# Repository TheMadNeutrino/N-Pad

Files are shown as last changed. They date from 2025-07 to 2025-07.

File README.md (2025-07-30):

N-Pad

The N-Pad is a 7-key macropad, equipped with a rotary encoder, OLED screen and 16 addressable LEDs. The heart of this pad is XIAO RP2040, controlled via KMK firmware.
N-Pad compounds of 3 main elements: PCB, Bottom (main) part of the case and the top part.

Features:

    -6 + 1 keys with awesome functions
    -Rotary encoder to modify volume and MUTE function when pressed (the 7th key).
    -128x32 OLED screen displaying the volume level
    -16 addressable LEDs (6 right under the keys and rest and the back side of PCB for even brighter and smoother backlight, fancy light at the USB port too)
    - Years of big software updates coming!

Model of the N-Pad:

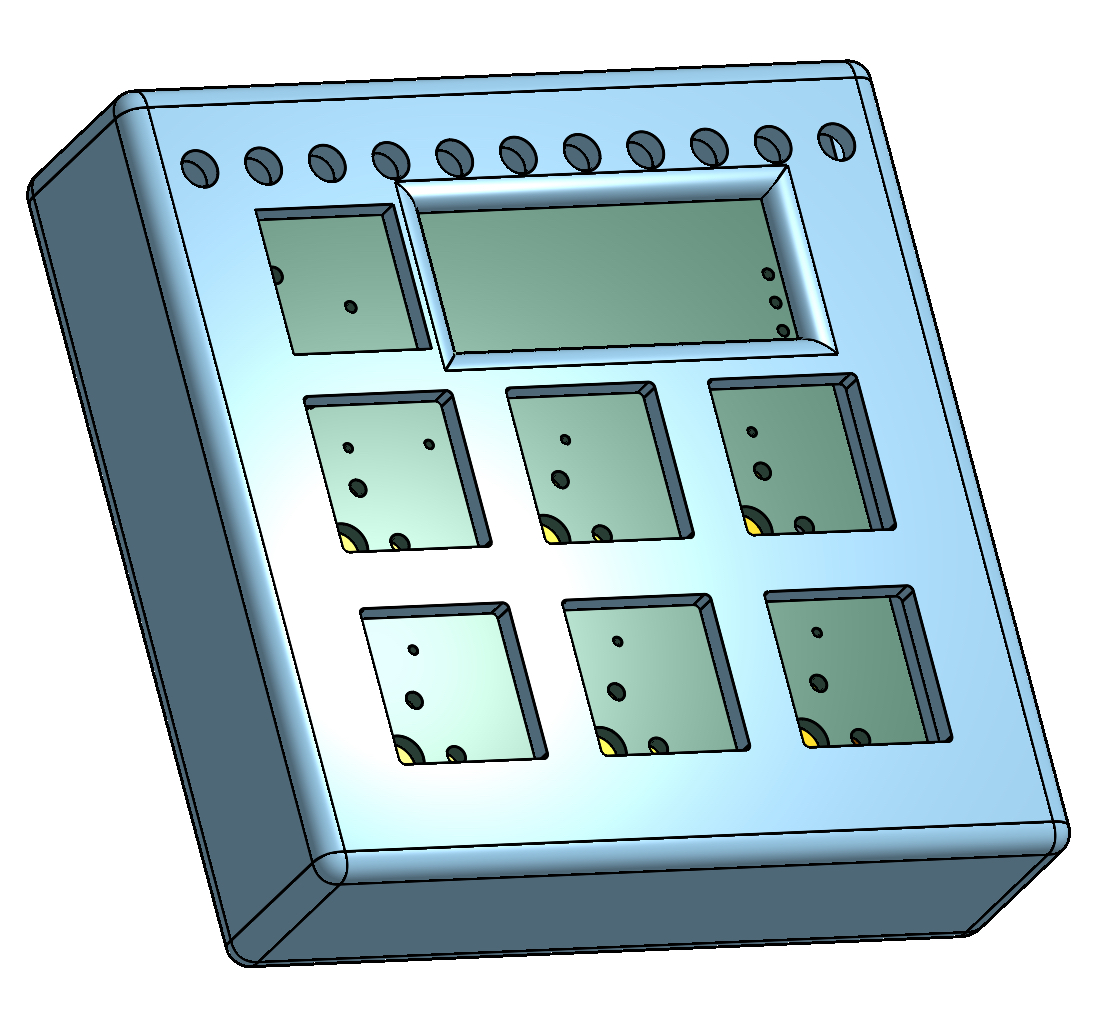
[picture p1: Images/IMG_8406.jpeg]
Model


The case is from 2 parts: The bottom part (includes space for PCB with raised platforms). The top has cutouts for key switches, rotary encoder as well as OLED screen and can be easily taken off.

Bottom part:
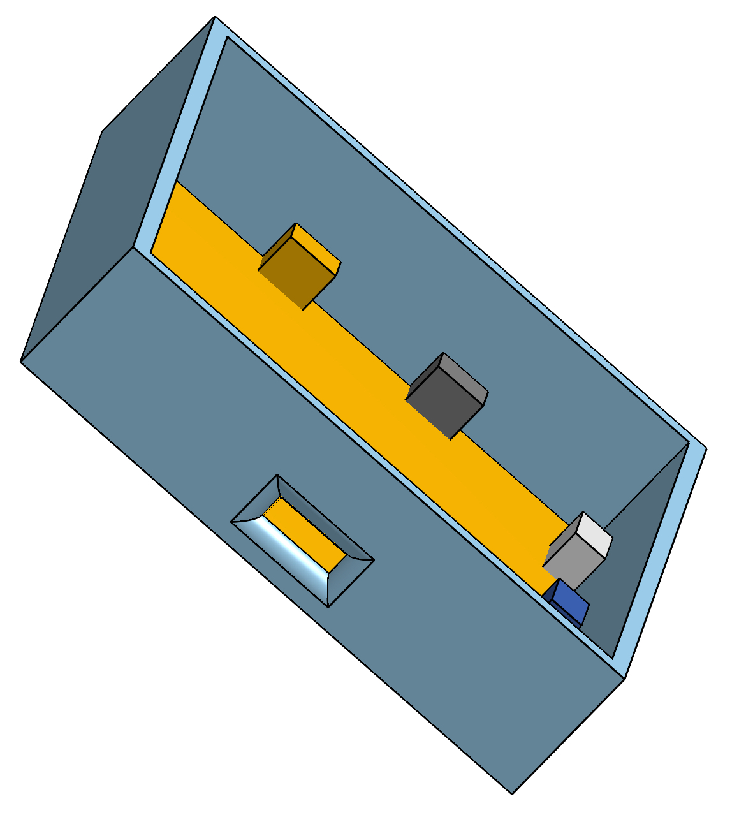
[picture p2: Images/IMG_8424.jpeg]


Top part (shown from the back side):
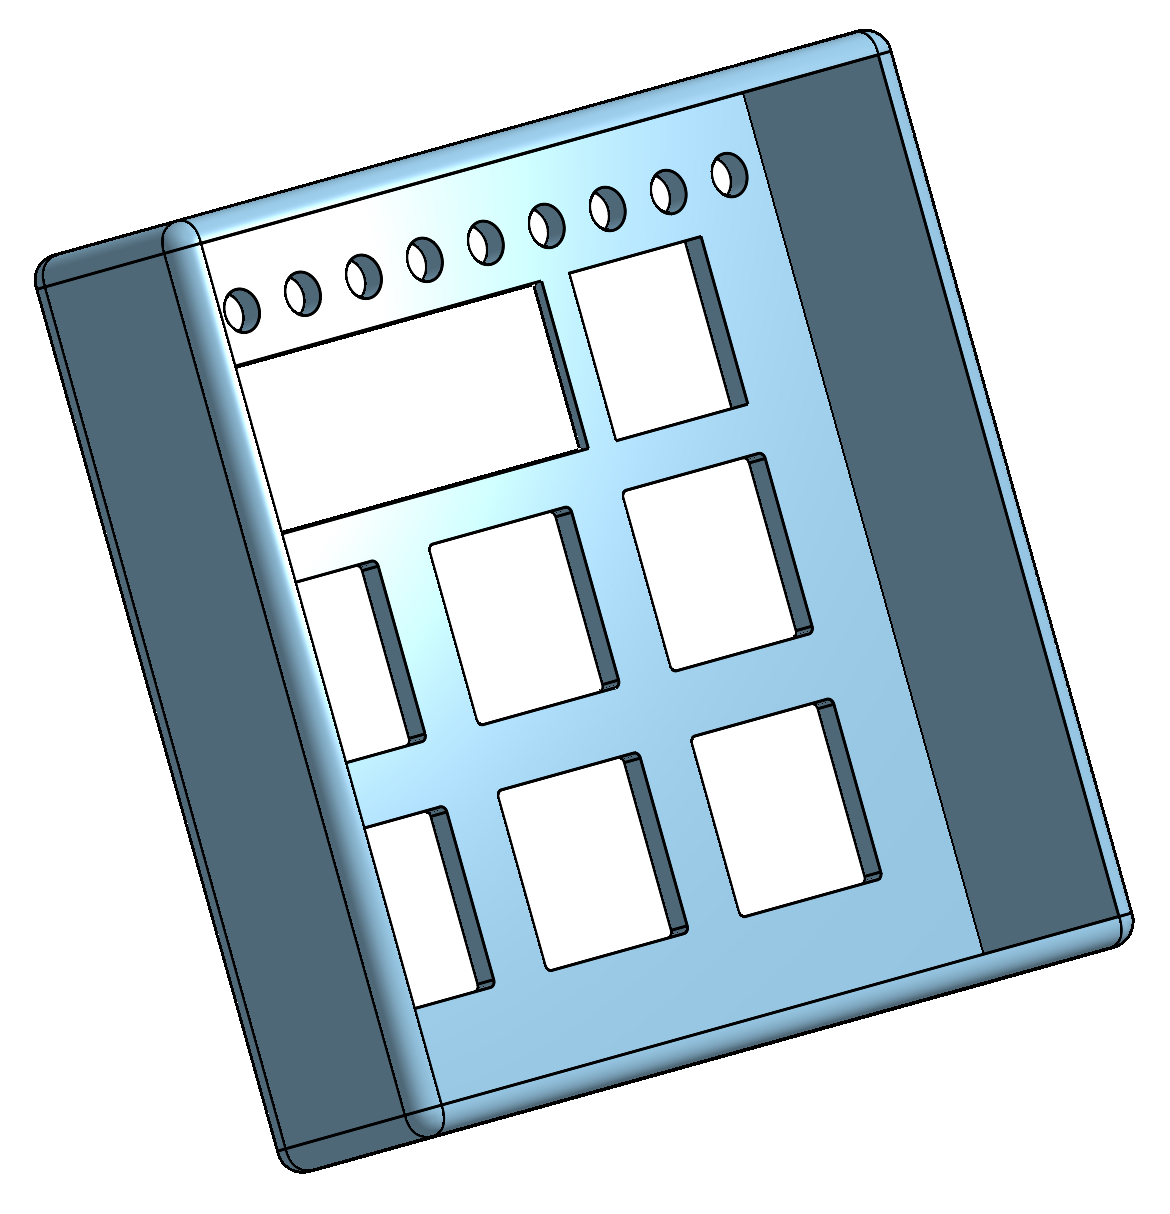
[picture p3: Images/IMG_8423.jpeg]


Thanks to the detachable design, no screws are needed for assembly.

Note: The first image shown a PCB with no parts on it, though contacts for keys visible. Designed in OnShape.

PCB:

PCB was designed in KiCad, consists of two layers.

Schematic:
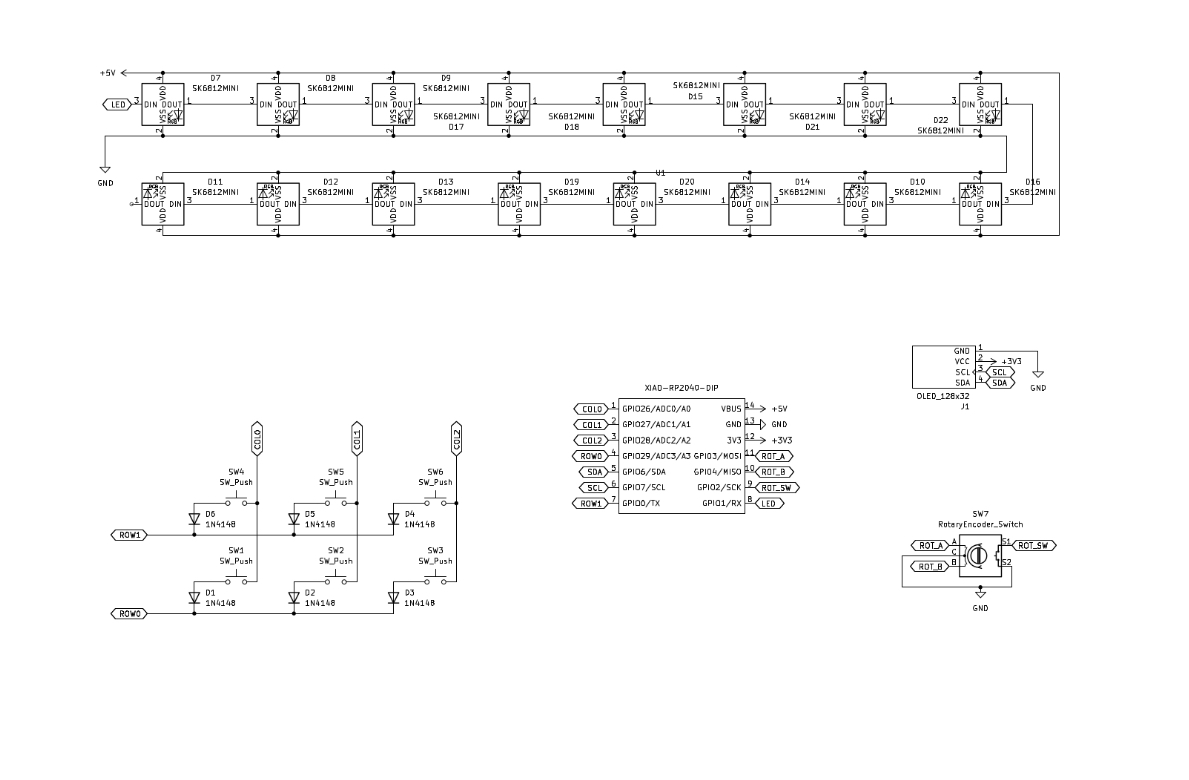
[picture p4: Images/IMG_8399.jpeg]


PCB:
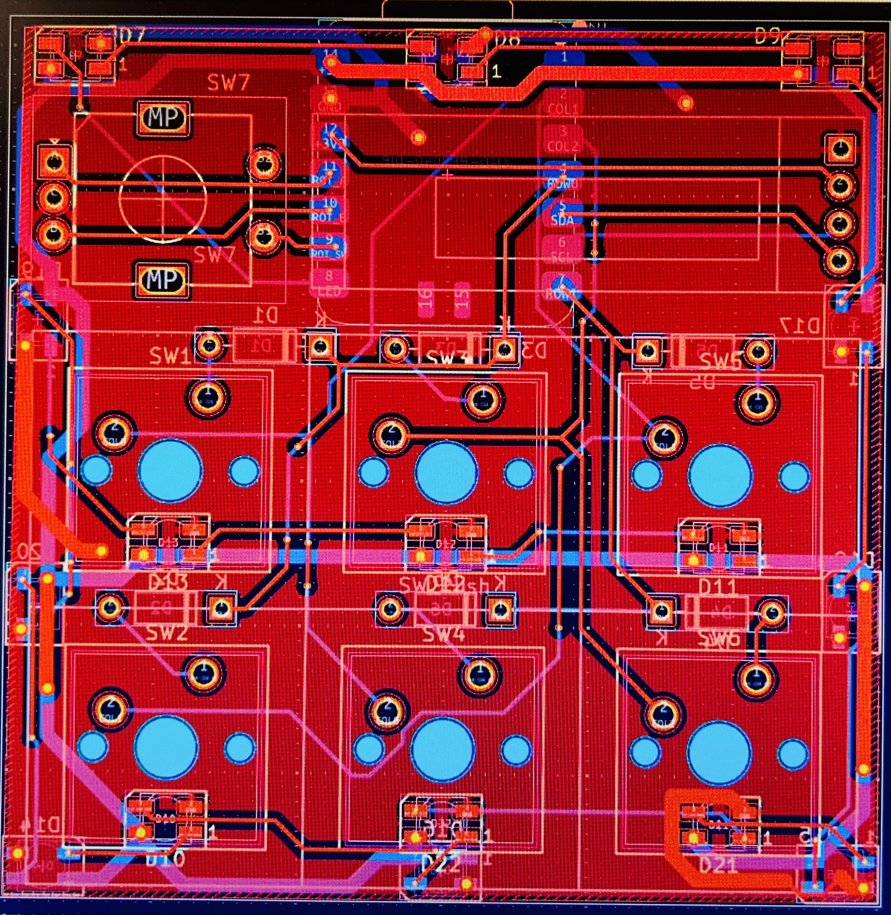
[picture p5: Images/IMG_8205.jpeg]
PCB


Firmware:

The N-Pad uses KMK firmware, loads of software updates coming, stay tuned!

Keys curretnly represents these functions: Copy, Paste, Homescreen, Play/Pause, Undo, Save

BOM:

    6 Cherry MX Switches

    6 DSA Keycaps
    
    6 1N4148 DO-35 Diodes.
    
    16 WS2812B LEDs 
    
    1 0.91" 128x32 OLED Display
    
    1 EC11 Rotary Encoder
    
    1 XIAO RP2040
    
    1 PCB
    
    1 Case (2 printed parts - detachable design - see CAD and Production folders)

Designed in the UK, (will be) assembled in the Czech Republic, EU, with parts from more than one country (living in the Czech Republic but currently on a UK trip)

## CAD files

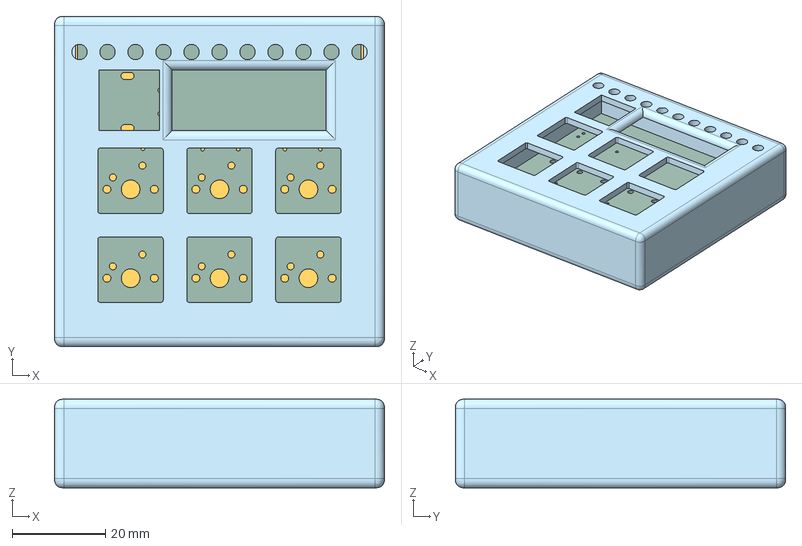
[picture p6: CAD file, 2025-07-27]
CAD/case.step
70.7 x 70.8 x 19.0 mm
pad_PCB

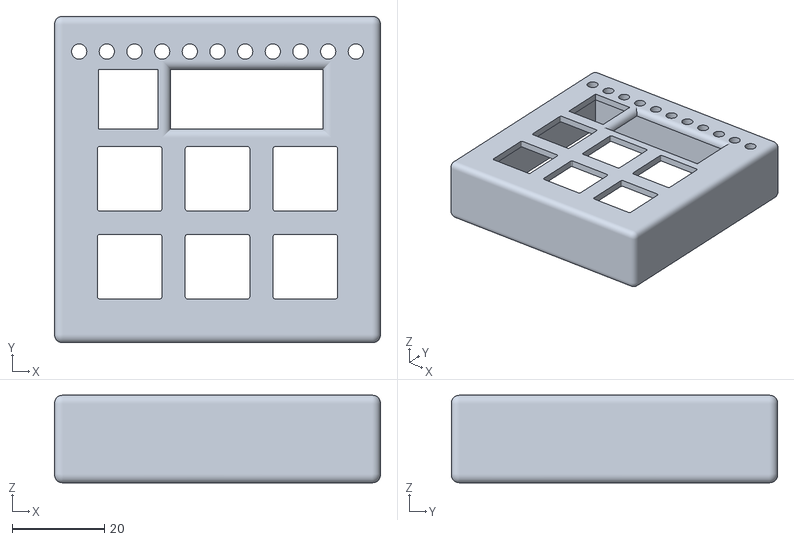
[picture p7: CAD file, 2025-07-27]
Production/top.stl
70.7 x 70.8 x 19.0

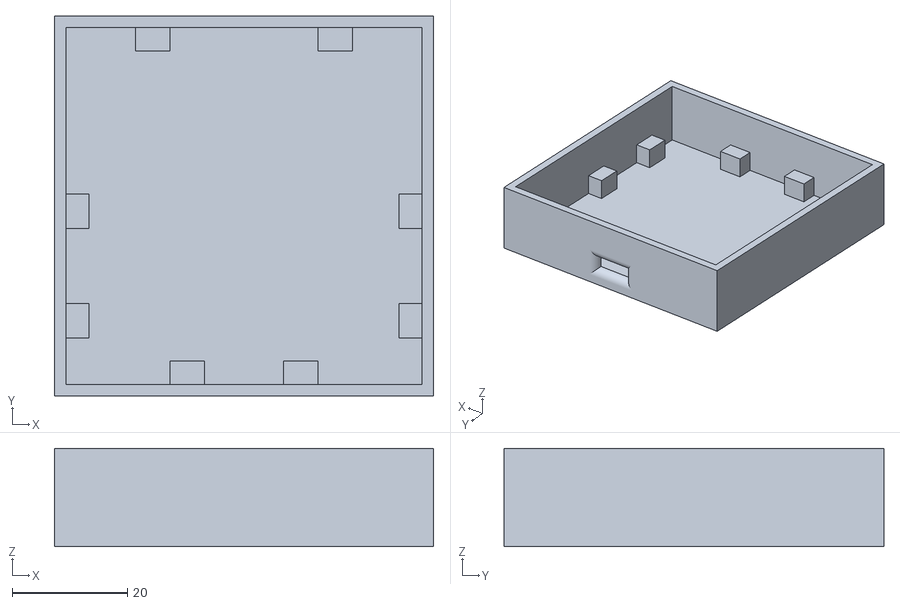
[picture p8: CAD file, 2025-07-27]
Production/bottom.stl
65.7 x 65.8 x 17.0

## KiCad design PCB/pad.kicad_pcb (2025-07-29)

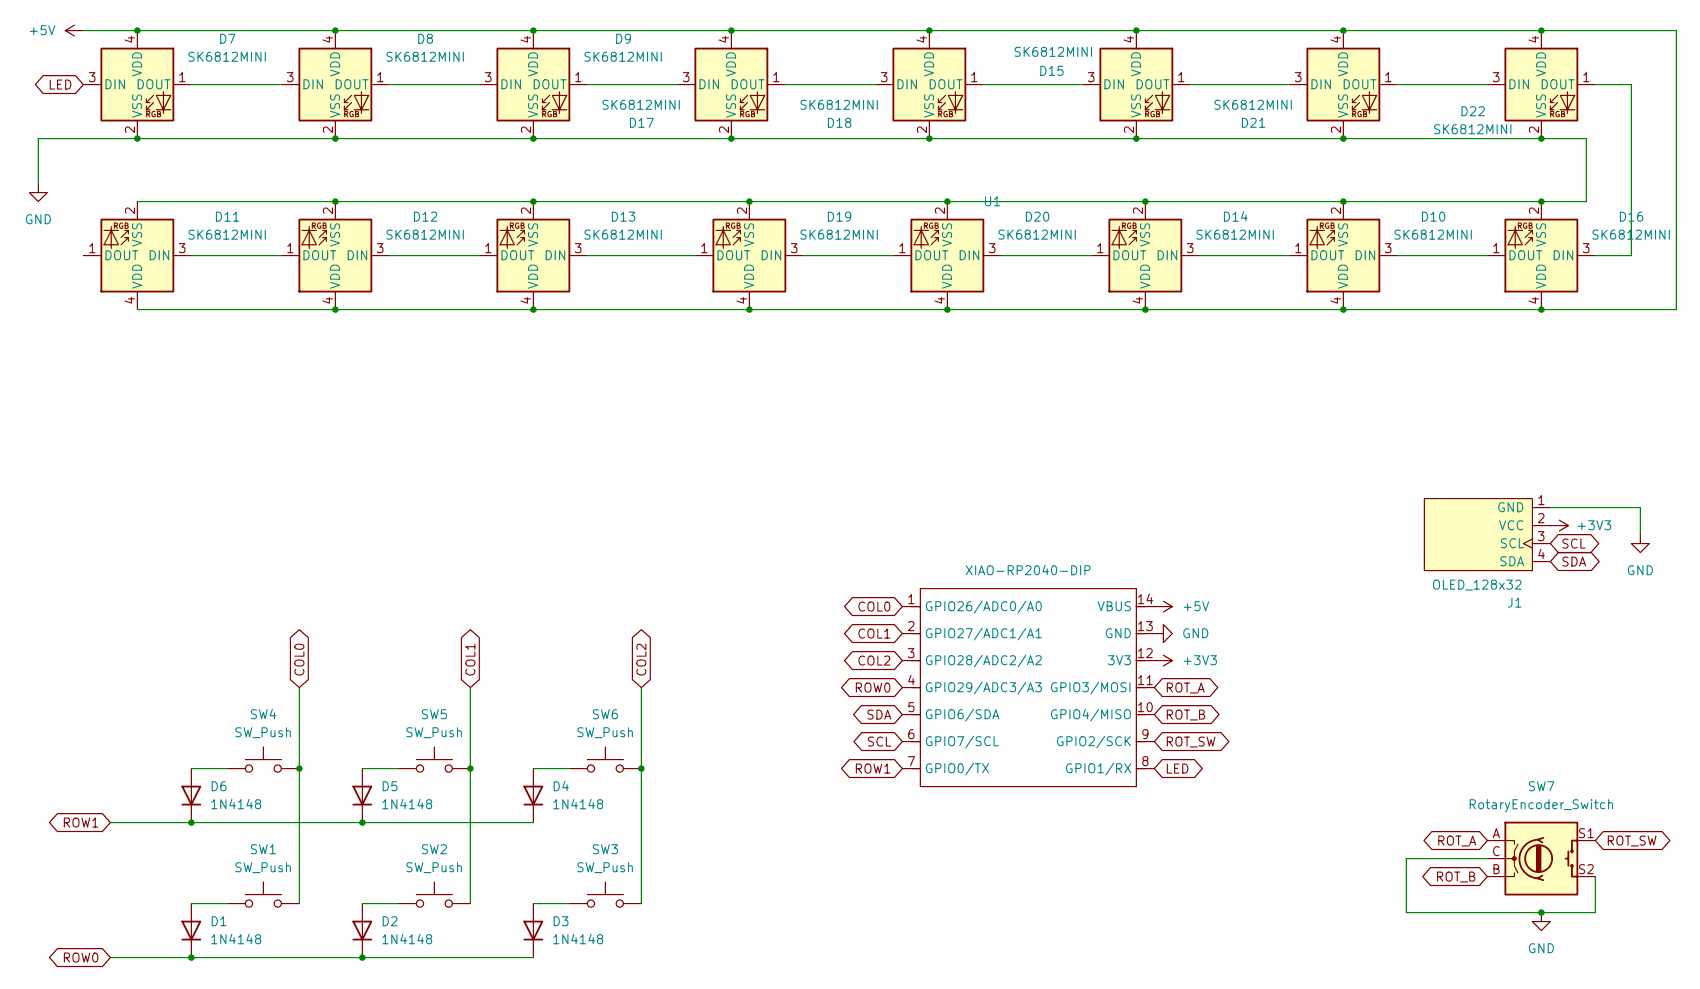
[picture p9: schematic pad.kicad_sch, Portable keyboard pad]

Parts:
D1, D2, D3, D4, D5, D6: 1N4148; D_DO-35_SOD27_P7.62mm_Horizontal
D7, D8, D9, D10, D11, D12, D13, D14, D15, D16, D17, D18, D19, D20, D21, D22: SK6812MINI; LED_SK6812MINI_PLCC4_3.5x3.5mm_P1.75mm
J1: OLED_128x32
SW1, SW2, SW3, SW4, SW5, SW6: SW_Push; SW_Cherry_MX_1.00u_PCB
SW7: RotaryEncoder_Switch; RotaryEncoder_Alps_EC11E-Switch_Vertical_H20mm
U1: XIAO-RP2040-DIP; XIAO-RP2040-SMD

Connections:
+3V3: J1.2 (VCC), U1.12 (3V3)
+5V: D7.4 (VDD), D8.4 (VDD), D9.4 (VDD), D10.4 (VDD), D11.4 (VDD), D12.4 (VDD), D13.4 (VDD), D14.4 (VDD), D15.4 (VDD), D16.4 (VDD), D17.4 (VDD), D18.4 (VDD), D19.4 (VDD), D20.4 (VDD), D21.4 (VDD), D22.4 (VDD), U1.14 (VBUS)
COL0: SW1.2, SW4.2, U1.1 (GPIO26/ADC0/A0)
COL1: SW2.2, SW5.2, U1.2 (GPIO27/ADC1/A1)
COL2: SW3.2, SW6.2, U1.3 (GPIO28/ADC2/A2)
GND: D7.2 (VSS), D8.2 (VSS), D9.2 (VSS), D10.2 (VSS), D11.2 (VSS), D12.2 (VSS), D13.2 (VSS), D14.2 (VSS), D15.2 (VSS), D16.2 (VSS), D17.2 (VSS), D18.2 (VSS), D19.2 (VSS), D20.2 (VSS), D21.2 (VSS), D22.2 (VSS), J1.1 (GND), SW7.C, SW7.S2, U1.13 (GND)
LED: D7.3 (DIN), U1.8 (GPIO1/RX)
unnamed: D1.2 (A), SW1.1
unnamed: D2.2 (A), SW2.1
unnamed: D3.2 (A), SW3.1
unnamed: D4.2 (A), SW6.1
unnamed: D5.2 (A), SW5.1
unnamed: D6.2 (A), SW4.1
unnamed: D7.1 (DOUT), D8.3 (DIN)
unnamed: D8.1 (DOUT), D9.3 (DIN)
unnamed: D10.3 (DIN), D16.1 (DOUT)
unnamed: D10.1 (DOUT), D14.3 (DIN)
unnamed: D11.3 (DIN), D12.1 (DOUT)
unnamed: D12.3 (DIN), D13.1 (DOUT)
unnamed: D13.3 (DIN), D19.1 (DOUT)
unnamed: D14.1 (DOUT), D20.3 (DIN)
unnamed: D15.3 (DIN), D18.1 (DOUT)
unnamed: D15.1 (DOUT), D21.3 (DIN)
unnamed: D16.3 (DIN), D22.1 (DOUT)
unnamed: D9.1 (DOUT), D17.3 (DIN)
unnamed: D17.1 (DOUT), D18.3 (DIN)
unnamed: D19.3 (DIN), D20.1 (DOUT)
unnamed: D21.1 (DOUT), D22.3 (DIN)
ROT_A: SW7.A, U1.11 (GPIO3/MOSI)
ROT_B: SW7.B, U1.10 (GPIO4/MISO)
ROT_SW: SW7.S1, U1.9 (GPIO2/SCK)
ROW0: D1.1 (K), D2.1 (K), D3.1 (K), U1.4 (GPIO29/ADC3/A3)
ROW1: D4.1 (K), D5.1 (K), D6.1 (K), U1.7 (GPIO0/TX)
SCL: J1.3 (SCL), U1.6 (GPIO7/SCL)
SDA: J1.4 (SDA), U1.5 (GPIO6/SDA)

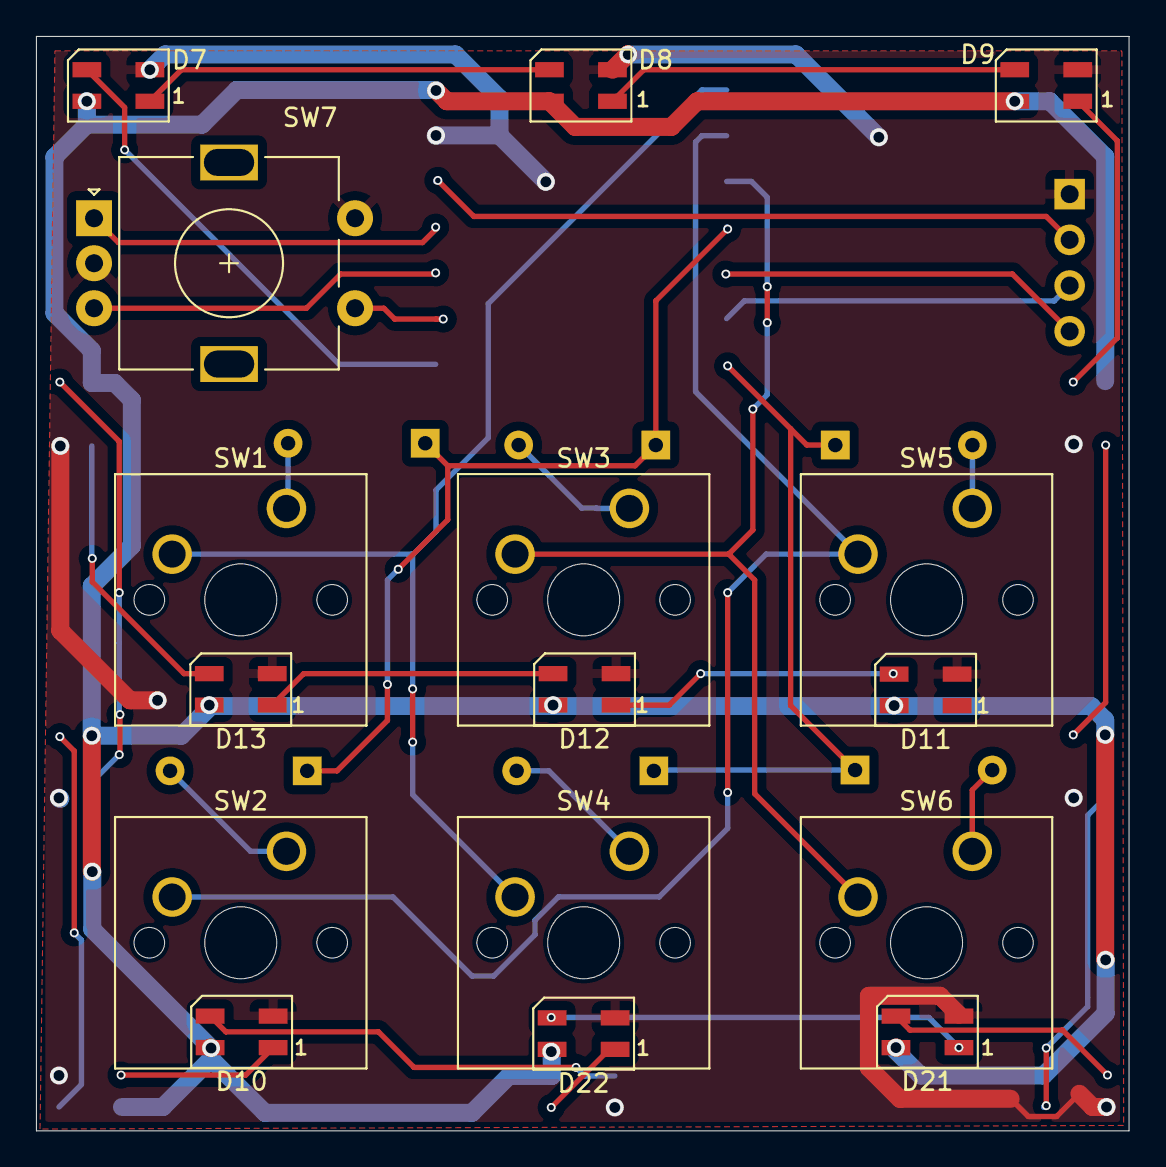
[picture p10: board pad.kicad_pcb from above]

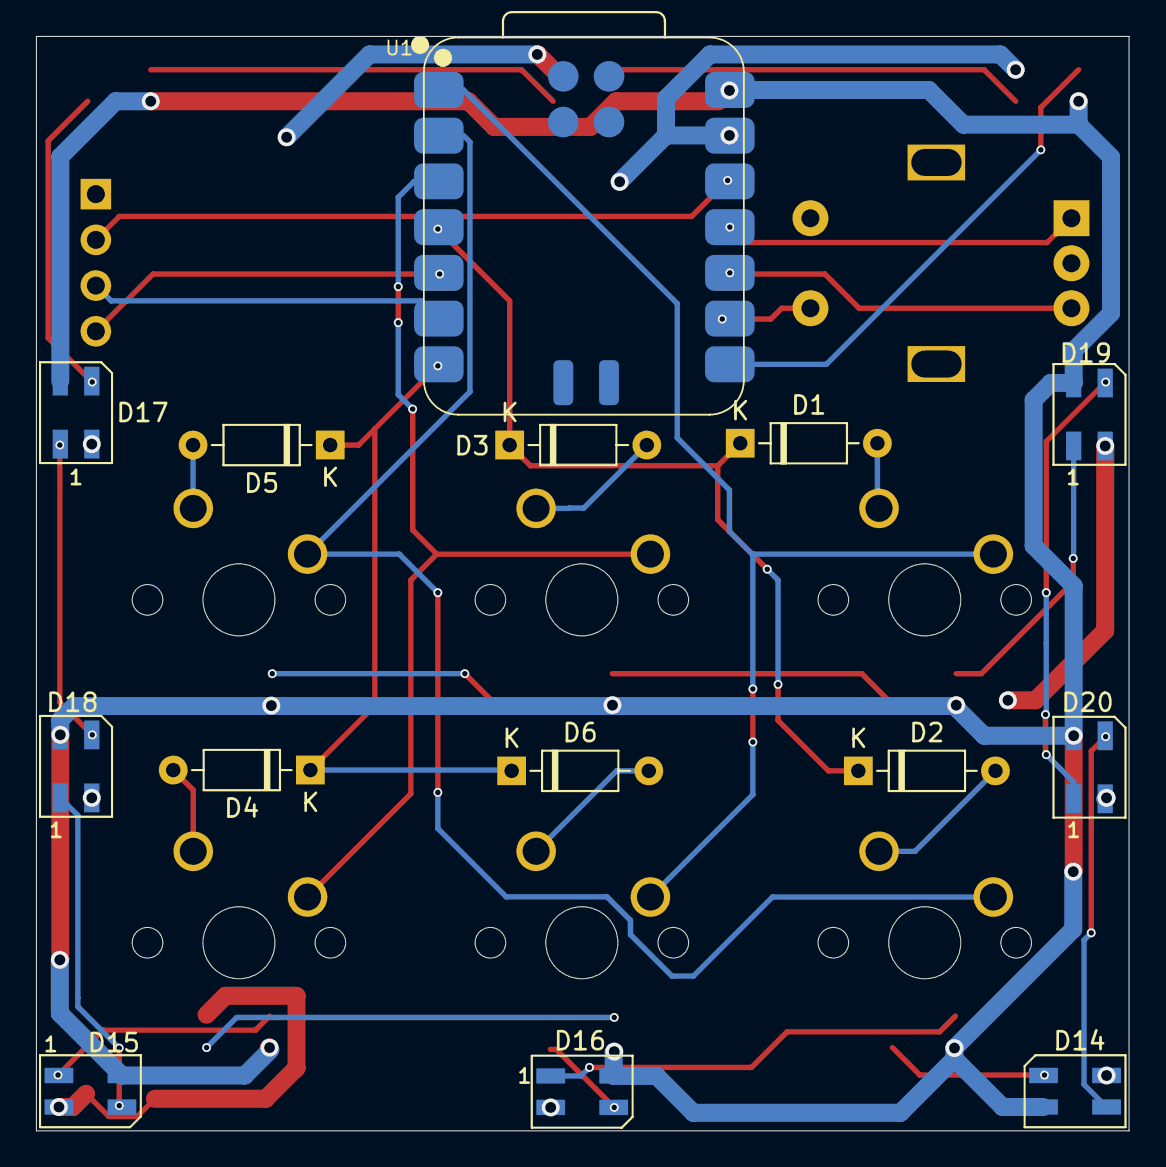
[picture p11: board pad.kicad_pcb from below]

Board: 2 copper layers, 60.7 x 60.8 mm, 31 parts (14 on the bottom side), 35 nets.

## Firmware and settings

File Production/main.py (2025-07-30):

import board
import digitalio
import neopixel
from kmk.kmk_keyboard import KMKKeyboard
from kmk.keys import KC
from kmk.scanners import DiodeOrientation
from kmk.extensions.peg_oled_display import Oled,OledDisplayMode,OledReactionType, OledReaction
from kmk.extensions.media_keys import MediaKeys
from kmk.extensions.rgb import RGB
from kmk.modules.encoder import EncoderHandler


keyboard = KMKKeyboard()

encoder_handler = EncoderHandler()
keyboard.modules.append(encoder_handler)

encoder_handler.pins = ((board.D3, board.D4), board.D2)

keyboard.volume = 35 # Start volume
keyboard.is_muted = False

def vol_up():
    if keyboard.volume < 100:
        keyboard.volume += 5
    keyboard.is_muted = False
    return KC.VOLU

def vol_down():
    if keyboard.volume > 0:
        keyboard.volume -= 5
    keyboard.is_muted = False
    return KC.VOLD

def toggle_mute():
    keyboard.is_muted = not keyboard.is_muted
    return KC.MUTE

encoder_handler.map = [((vol_up, vol_down), toggle_mute)]


def draw_volume(oled):
    from kmk.handlers.sequences import simple_key_sequence
    from kmk.keys import KC

    if keyboard.is_muted:
        oled.write("Mute")
    else:
        oled.write(f"Volume: {keyboard.volume}")

# OLED settings
oled_ext = Oled(
    i2c=board.I2C(),  # Uses D6, D7
    width=128,
    height=32,
    to_display=draw_volume,
    flip=False,
    display_mode=OledDisplayMode.MASTER
)

keyboard.extensions.append(oled_ext)


# Define keys matrix
keyboard.col_pins = (board.A0, board.A1, board.A2)
keyboard.row_pins = (board.D29, board.D0)

keyboard.diode_orientation = DiodeOrientation.COL2ROW

keyboard.extensions.append(MediaKeys())

# LEDs
rgb = RGB(pixel_pin=board.D1, num_pixels=16, hue_default=64)
keyboard.extensions.append(rgb)

keyboard.keymap = [
    [
        KC.CTRL_C,              # copy
        KC.WIN_D,               # homescreen
        KC.CTRL_V,              # paste
        KC.MEDIA_PLAY_PAUSE,    # Play/Pause
        KC.CTRL_Z,              # Undo
        KC.CTRL_S               # Save
    ]
]


if __name__ == '__main__':
    keyboard.go()
